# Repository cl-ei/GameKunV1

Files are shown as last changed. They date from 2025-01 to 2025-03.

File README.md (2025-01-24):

# GameKunV1
Magic Revised Tetris Palm

### 简介

这是一款魔改版的俄罗斯方块掌机，移除了原主板，换上了自制主板。自制主板选用高性能的 stm32H7 作为主控，通过电阻分压网络驱动液晶屏，还添加了 TAS2563 音频功放芯片来驱动扬声器，实现了声色俱全的效果，支持编写自制游戏。

This is a modified version of the Tetris handheld game console. The original motherboard has been removed and replaced with a self - made one. The self - made motherboard uses the high - performance STM32H7 as the main control unit. It drives the liquid crystal display through a resistor voltage - dividing network. Additionally, a TAS2563 audio power amplifier chip is added to drive the speaker, achieving a full - fledged audio - visual effect. It also supports the development of self - made games.

图纸有几处错误：
1. 音频功放的部分使用SAI接口，但若使用H723芯片，则该接口对应的SAI模块不支持半传输DMA中断，因此使用跳线连接到I2S1接口；
2. 原本预留了一个ADC通道，用于连接模拟麦克风，但若使用H723芯片，对应通道不支持半传输中断；
3. 主板上集成一颗MPU6050传感器，但电路绘制错误，芯片焊上不可用；
3. 没有兼容原机的电池座

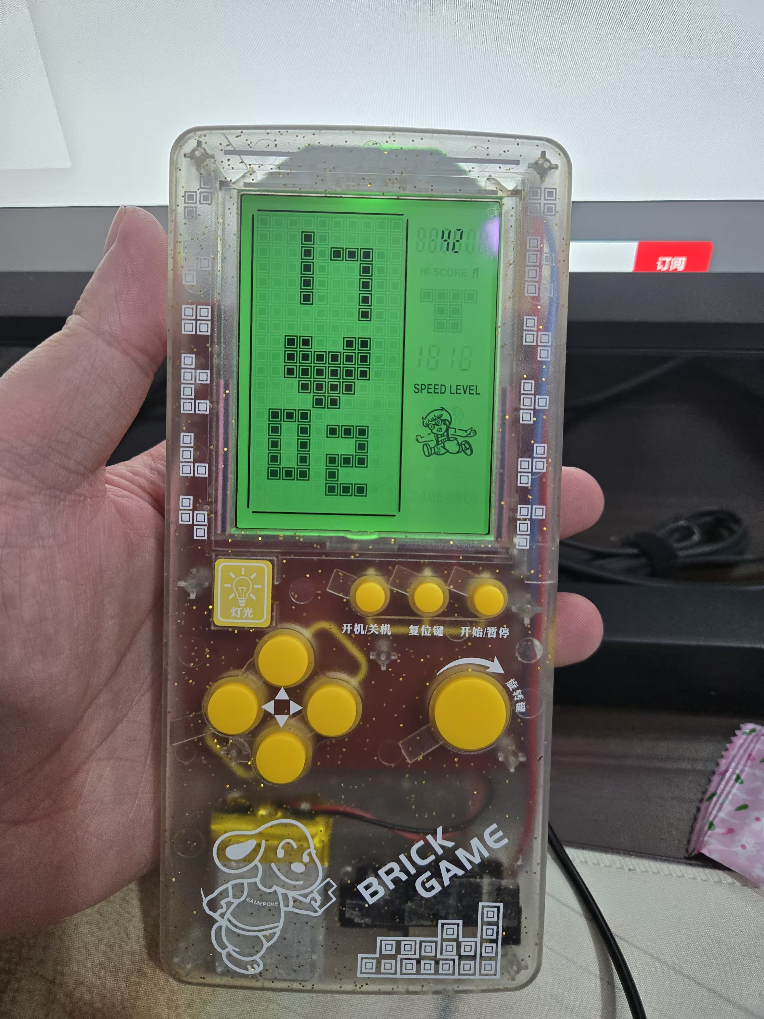
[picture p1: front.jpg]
预览

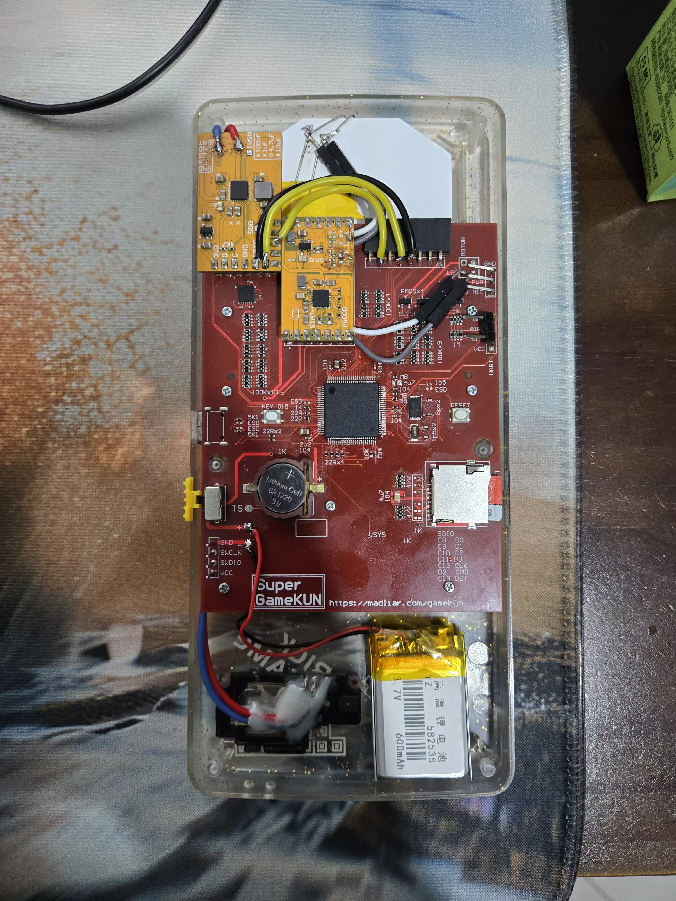
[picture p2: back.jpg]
预览2


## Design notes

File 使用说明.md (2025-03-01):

预览

1. 开/关机

推动右侧开关，自动进入开机模式，展示时钟。时钟会自动同步网络时间，保持精准。

2. 连接网络

用Type-C数据线连接电脑，然后按住“开始/暂停键”，直到屏幕显示USB图标，此时电脑上会多出一个大容量存储的设备。此过程可能较为漫长，需耐心等待。

打开大容量存储设备，根目录下会有一个“wifi.txt”文件（若没有，就自行创建），文件名区分大小写。在这个文件内写入WiFi的名称（ssid）和密码，用“*”相隔。注意WiFi名不可以包含英文星号“*”。

例如，WiFi名为“madliar”，密码为“password”，则在文件内写入“madliar*password”。又如，WiFi名称为“madliar”，密码为“1234*abc”，则在文件内写入“madliar*1234*abc”。

保存之后，按住“开始/暂停键”，退出USB模式后，重新开关机，即可以自动联网获取时间。

在首次开机时，系统会自动同步网络时间，此后每间隔2小时同步一次。同步成功时，设备后部顶端的LED灯会闪烁。

3. 手动调整时间

在时钟模式下，长按“复位键”，小时数会闪烁。此时按上、下键调整数字。再短按复位键，分钟数开始闪烁，按照同样的方法调整分钟，再按复位键，会退回到时钟模式。

4. MP3功能

时钟模式下，按住“旋转键”会进入音乐播放器模式。此时上下键调整音量，左右键切换歌曲，旋转键控制播放、暂停。再次长按旋转键，系统退出MP3播放器。

使用2中链接到电脑的方式，可以从电脑上下载音乐到设备中，但需注意，此设备仅支持wav格式，码率为44.1Khz或48Khz。

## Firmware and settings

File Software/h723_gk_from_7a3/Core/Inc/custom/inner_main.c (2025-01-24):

#include "inner_main.h"
#include "stm32h7xx_hal.h"
#include "debug.h"

#include "usb_device.h"
#include "usbd_msc.h"
#include "usbd_desc.h"
#include "usbd_storage_if.h"

#include "custom/ff15/ff.h"

#include "tas2563.h"
#include "logic/display.h"
#include "logic/mevent.h"
#include "logic/maudio.h"

extern TIM_HandleTypeDef htim3;
extern RTC_HandleTypeDef hrtc;


u8 sysHour = 0;
u8 sysMin = 0;
u8 sysSec = 0;
u16 sysMicSec = 0;
u8 sysBtnTick = 0;

void HAL_TIM_PeriodElapsedCallback(TIM_HandleTypeDef *htim) {
	if (htim->Instance == TIM3){
		// every 1ms
		sysMicSec++;
		if (sysMicSec >= 1000) {
			sysMicSec = 0;
			sysSec++;
			if (sysSec >= 60) {
				sysSec = 0;
				sysMin++;
				if (sysMin >= 60) {
					sysMin=0;
					sysHour++;
					if (sysHour >= 24) {
						sysHour = 0;
					}
				}
			}
		}

		// check button
		sysBtnTick++;
		if (sysBtnTick >= 3) {
			sysBtnTick = 0;
			Event_CheckButton();
		}

		// flush lcd
		SegLcd_DrawOneFrame();
	}
}

// USB
extern USBD_HandleTypeDef hUsbDeviceHS;

i8 CL_USB_DEVICE_Init(void) {
	if (USBD_Init(&hUsbDeviceHS, &HS_Desc, DEVICE_HS) != USBD_OK) {
		return -1;
	}
	if (USBD_RegisterClass(&hUsbDeviceHS, &USBD_MSC) != USBD_OK) {
		return -1;
	}
	if (USBD_MSC_RegisterStorage(&hUsbDeviceHS, &USBD_Storage_Interface_fops_HS) != USBD_OK) {
		return -1;
	}

	if (USBD_Start(&hUsbDeviceHS) != USBD_OK) {
		return -1;
	}
	HAL_PWREx_EnableUSBVoltageDetector();
	return 0;
}


i8 CL_USB_Device_DeInit() {
	HAL_PWREx_DisableUSBVoltageDetector ();

	if (USBD_Stop(&hUsbDeviceHS) != 0) {
		return -1;
	}
	return USBD_DeInit(&hUsbDeviceHS);
}

i8 SetSysFreq(u8 isHigh) {
	u8 rst = 0;

	HAL_PWREx_ConfigSupply(PWR_LDO_SUPPLY);
	if (isHigh) {
		__HAL_PWR_VOLTAGESCALING_CONFIG(PWR_REGULATOR_VOLTAGE_SCALE0);
	} else {
		__HAL_PWR_VOLTAGESCALING_CONFIG(PWR_REGULATOR_VOLTAGE_SCALE3);
	}

	while(!__HAL_PWR_GET_FLAG(PWR_FLAG_VOSRDY)) {}

	// config pll
	RCC_ClkInitTypeDef RCC_ClkInitStruct = {0};
	RCC_ClkInitStruct.ClockType = RCC_CLOCKTYPE_HCLK|RCC_CLOCKTYPE_SYSCLK
								  |RCC_CLOCKTYPE_PCLK1|RCC_CLOCKTYPE_PCLK2
								  |RCC_CLOCKTYPE_D3PCLK1|RCC_CLOCKTYPE_D1PCLK1;
	RCC_ClkInitStruct.SYSCLKSource = RCC_SYSCLKSOURCE_PLLCLK;

	if (isHigh) {
	  RCC_ClkInitStruct.SYSCLKDivider = RCC_SYSCLK_DIV1;
	} else {
	  RCC_ClkInitStruct.SYSCLKDivider = RCC_SYSCLK_DIV16;
	}

	RCC_ClkInitStruct.AHBCLKDivider = RCC_HCLK_DIV2;
	RCC_ClkInitStruct.APB3CLKDivider = RCC_APB3_DIV2;
	RCC_ClkInitStruct.APB1CLKDivider = RCC_APB1_DIV2;
	RCC_ClkInitStruct.APB2CLKDivider = RCC_APB2_DIV2;
	RCC_ClkInitStruct.APB4CLKDivider = RCC_APB4_DIV2;
	if (isHigh) {
		rst = HAL_RCC_ClockConfig(&RCC_ClkInitStruct, FLASH_LATENCY_3);
	} else {
		rst = HAL_RCC_ClockConfig(&RCC_ClkInitStruct, FLASH_LATENCY_0);
	}
	if (rst != HAL_OK) {
		print("sys clk config error: %d", rst);
		return -1;
	}
	print("sys clk config ok.");

	// 需要设置 TIM3的频率
	HAL_TIM_Base_Stop_IT(&htim3);
	HAL_TIM_Base_DeInit(&htim3);

	TIM_ClockConfigTypeDef sClockSourceConfig = {0};
	TIM_MasterConfigTypeDef sMasterConfig = {0};

	htim3.Instance = TIM3;
	if (isHigh) {
		htim3.Init.Prescaler = 240-1;
	} else {
		htim3.Init.Prescaler = 15-1;
	}

	htim3.Init.CounterMode = TIM_COUNTERMODE_UP;
	htim3.Init.Period = 1000;
	htim3.Init.ClockDivision = TIM_CLOCKDIVISION_DIV1;
	htim3.Init.AutoReloadPreload = TIM_AUTORELOAD_PRELOAD_ENABLE;
	rst = HAL_TIM_Base_Init(&htim3);
	if (rst != HAL_OK) {
		print("tim error: %d", rst);
		return -1;
	}

	sClockSourceConfig.ClockSource = TIM_CLOCKSOURCE_INTERNAL;
	rst = HAL_TIM_ConfigClockSource(&htim3, &sClockSourceConfig);
	if (rst != HAL_OK) {
		print("tim clk config error: %d", rst);
		return -1;
	}

	sMasterConfig.MasterOutputTrigger = TIM_TRGO_RESET;
	sMasterConfig.MasterSlaveMode = TIM_MASTERSLAVEMODE_DISABLE;
	rst = HAL_TIMEx_MasterConfigSynchronization(&htim3, &sMasterConfig);
	if (rst != HAL_OK) {
		print("tim master config result: %d", rst);
	    return -1;
	}
	HAL_TIM_Base_Start_IT(&htim3);
	return 0;
}

// mode 0: rest
// 1. play
#define PLAYMODE_MAIN_PAGE  0
#define PLAYMODE_MP3        1
#define PLAYMODE_HOUR_SET_PAGE  2
#define PLAYMODE_MIN_SET_PAGE  3
#define PLAYMODE_USB_PAGE  4

u32 playMode = PLAYMODE_MAIN_PAGE;
u8 Mp3_SongCount = 0;
u8 Mp3_SongIndex = 0;
u8 Mp3_Volume = 2;

void Mp3_SetVol() {
	SegLcd_SetLevelValue(Mp3_Volume, 0);
	Audio_SetVol(Mp3_Volume);
}
extern u8 SegLcd_ShowMusic;
extern u8 SegLcd_Body;
extern u8 SegLcd_PrevBox;

i8 Mp3_Enter() {
	SegLcd_ShowMusic = 1;
	SegLcd_Body = 0;

	u8 result = Audio_Init();
	print("audio init result: %d", result);
	if (result != 0) {
		return result;
	}

	Mp3_SongCount = Audio_GetSongCount();
	SegLcd_SetTopValue(0, 2);
	result = Audio_Start(Mp3_SongIndex);
	if (result == 0) {
		Mp3_SetVol();
	}
	return result;
}

i8 Mp3_Exit() {
	SegLcd_ShowMusic = 0;
	SegLcd_Body = 0b101;
	SegLcd_PrevBox = 0;

	Scr_Clean();
	Scr_RenderTime(88, 88, 88); // 清除缓存，下次渲染刷新真实值
	SegLcd_SetLevelValue(Mp3_Volume, 1);
	i8 result = Audio_Stop();
	if (result != 0) {
		print("stop audio error: %d", result);
		return result;
	}
	return result;
}


u8 uartTxBuff[65];
u8 uartRxBuff[64];
u8 wifiConfLen = 0;
extern UART_HandleTypeDef huart2;

// 0 准备开机设置时间; 1. 等待m5开机; 2 发送并进入3; 3 检查时间，如果超过1个小时，则进入0 开始重新校准
u8 m5Status = 0;
u32 m5Tick = 0;

void HAL_UARTEx_RxEventCallback(UART_HandleTypeDef *huart, uint16_t Size) {
	if(huart == (&huart2)) {
		print("s: %d", Size);
		if (Size == 3 &&
			(uartRxBuff[0] & 0xC0) == 0xC0 &&
			(uartRxBuff[1] & 0x80) == 0x80 &&
			(uartRxBuff[2] & 0x40) == 0x40) {

			sysHour = uartRxBuff[0] & (~0xC0);
			sysMin = uartRxBuff[1] & (~0x80);
			sysSec = uartRxBuff[2] & (~0x40);
			m5Status = 4;
		}
		HAL_UARTEx_ReceiveToIdle_DMA(&huart2, uartRxBuff, 32);
	}
}

void CheckNetTime(u32 tick) {
	u8 rst = 0;

	// 准备
	if (m5Status == 0) {
		m5Status = 1;
		HAL_GPIO_WritePin(GPIOA, GPIO_PIN_15, GPIO_PIN_RESET);
		m5Tick = tick;
	} else if (m5Status == 1) {
		if ((tick - m5Tick) > 5000) {
			m5Status = 2;
		}
	} else if (m5Status == 2) {
		for (i8 i = 0; i < 8; i++) {
			rst = HAL_UART_Receive(&huart2, uartRxBuff, 32, 0x1);
			print("receive rst: %d");
			if (rst != 0) {
				break;
			}
		}
		rst = HAL_UARTEx_ReceiveToIdle_DMA(&huart2, uartRxBuff, 32);
		print("set idle: %d", rst);

		rst = HAL_UART_Transmit(&huart2, uartTxBuff, wifiConfLen, 0xFFFF);
		print("wifi conf tx: %d, len: %d", rst, wifiConfLen);

		m5Status = 3;
	} else if (m5Status == 3) {
	} else if (m5Status == 4) {
		// close m5
		HAL_GPIO_WritePin(GPIOA, GPIO_PIN_15, GPIO_PIN_SET);

		RTC_TimeTypeDef realTime;
		realTime.Hours = sysHour;
		realTime.Minutes = sysMin;
		realTime.Seconds = sysSec;
		u8 rst = HAL_RTC_SetTime(&hrtc, &realTime, RTC_FORMAT_BIN);
		print("set ntp rst: %d", rst);

		m5Status = 5;
	} else if (m5Status == 5) {
		if ((tick - m5Tick) > (1000 * 7200)) {
			m5Status = 0;
		}
	}
}

i8 loadWifiPass() {
	FIL tmpFile;
	FRESULT fr;
	UINT br = 0;
	TCHAR fno[9] = {'w', 'i', 'f', 'i', '.', 't', 'x', 't', '\0'};

	u8 rst = Audio_Init();
	if (rst != 0) {
		print("mount err: %d", rst);
		return rst;
	}
	fr = f_open(&tmpFile, fno, FA_READ | FA_OPEN_EXISTING);
	if (fr != FR_OK) {
		print("open wifi conf err: %d", fr);
		return -1;
	}
	fr = f_read(&tmpFile, (void *)uartTxBuff, 63, &br); // 抛弃最起始的100个字节
	if (fr != FR_OK) {
		print("read err: %d", fr);
		return -1;
	}
	print("read br: %d", br);
	wifiConfLen = (br >= 63) ? 63 : br;
	uartTxBuff[64] = 0;
	print(uartTxBuff);
	return 0;
}

void CheckBgLight(u32 tick) {
	static u32 bgLightTick = 0;
	if (tick - bgLightTick > 200) {
		bgLightTick = tick;
		SegLcd_SetBGLight((Event_GetLastEventDur() < 15000) ? 1 : 0);
	}
}

u8 EventLoopMainPage() {
	u32 tick;
	u8 rst;
	u8 event;
	u8 retMode = 0;

	Scr_Clean();
	Scr_RenderTime(88, 88, 88); // 清除缓存，下次渲染刷新真实值

	rst = SetSysFreq(0);
	print("set low pwr rst: %d", rst);

	// update time
	RTC_TimeTypeDef realTime;
	RTC_DateTypeDef sDate;
	rst = HAL_RTC_GetTime(&hrtc, &realTime, RTC_FORMAT_BIN);
	HAL_RTC_GetDate(&hrtc, &sDate, RTC_FORMAT_BIN);
	sysHour = realTime.Hours;
	sysMin = realTime.Minutes;
	sysSec = realTime.Seconds;

	while (1) {
		tick = HAL_GetTick();
		CheckBgLight(tick);
		event = Event_Get();

		CheckNetTime(tick);
		Scr_RenderTime(sysHour, sysMin, sysSec);

		if (event == EVENT_KEY_SPIN_LONG) {
			rst = Mp3_Enter();
			if (rst == 0) {
				return PLAYMODE_MP3;
			} else {
				print("process error: %d", rst);
			}
		} else if (event == EVENT_KEY_RST_LONG) {
			return PLAYMODE_HOUR_SET_PAGE;
		} else if (event == EVENT_KEY_START_LONG) {
			return PLAYMODE_USB_PAGE;
		}
	}
}

u8 EventLoopMP3() {
	u32 tick;
	u8 rst;
	u8 event;

	rst = SetSysFreq(1);
	print("set high pwr rst: %d", rst);
	rst = Mp3_Enter();
	if (rst != 0) {
		return PLAYMODE_MAIN_PAGE;
	}
	while (1) {
		tick = HAL_GetTick();
		CheckBgLight(tick);
		event = Event_Get();

		Audio_RenderUI(tick);
		Audio_LoadBuff();

		if (event == EVENT_KEY_SPIN) {
			if(Audio_IsPlaying()){
				Audio_Pause();
			} else {
				Audio_Play();
			}
		} else if (event == EVENT_KEY_UP) {
			if (Mp3_Volume < 10) {
				Mp3_Volume++;
			}
			Mp3_SetVol();
		} else if (event == EVENT_KEY_DOWN) {
			if (Mp3_Volume > 0) {
				Mp3_Volume--;
			}
			Mp3_SetVol();
		} else if (event == EVENT_KEY_LEFT) {
			Audio_Stop();
			if (Mp3_SongIndex == 0) {
				Mp3_SongIndex = Mp3_SongCount - 1;
			} else {
				Mp3_SongIndex--;
			}
			Audio_Start(Mp3_SongIndex);
			SegLcd_SetTopValue(Mp3_SongCount*100 + Mp3_SongIndex + 1, 0);
		} else if (event == EVENT_KEY_RIGHT || event == EVENT_MUSIC_END) {
			Audio_Stop();
			Mp3_SongIndex++;
			if (Mp3_SongIndex >= Mp3_SongCount) {
				Mp3_SongIndex = 0;
			}
			Audio_Start(Mp3_SongIndex);
			SegLcd_SetTopValue(Mp3_SongCount*100 + Mp3_SongIndex + 1, 0);
		} else if (event == EVENT_KEY_SPIN_LONG) {
			rst = Mp3_Exit();
			if (rst == 0) {
				return PLAYMODE_MAIN_PAGE;
			} else {
				print("exit mp3 error: %d", rst);
			}
		}
	}
}

u8 EventLoopHourSet() {
	u32 tick;
	u8 event;

	SetSysFreq(0);

	while (1) {
		tick = HAL_GetTick();
		CheckBgLight(tick);
		event = Event_Get();

		Scr_FlashHourMin(tick, sysHour, sysMin, sysSec, 0);
		if (event == EVENT_KEY_RST) {
			return PLAYMODE_MIN_SET_PAGE;
		} else if (event == EVENT_KEY_UP) {
			sysHour = sysHour == 23 ? 0 : (sysHour + 1);
		} else if (event == EVENT_KEY_DOWN) {
			sysHour = sysHour == 0 ? 23 : (sysHour - 1);
		}
	}
}

u8 EventLoopMinSet() {
	u32 tick;
	u8 event;
	u8 rst;

	SetSysFreq(0);

	while (1) {
		tick = HAL_GetTick();
		CheckBgLight(tick);
		event = Event_Get();

		Scr_FlashHourMin(tick, sysHour, sysMin, sysSec, 1);

		if (event == EVENT_KEY_RST) {
			RTC_TimeTypeDef realTime;
			realTime.Hours = sysHour;
			realTime.Minutes = sysMin;
			realTime.Seconds = sysSec;
			rst = HAL_RTC_SetTime(&hrtc, &realTime, RTC_FORMAT_BIN);
			if (rst != 0) {
				print("set failed: %d", rst);
			} else {
				return PLAYMODE_MAIN_PAGE;
			}
		} else if (event == EVENT_KEY_UP) {
			sysMin = sysMin == 59 ? 0 : (sysMin + 1);
		} else if (event == EVENT_KEY_DOWN) {
			sysMin = sysMin == 0 ? 59 : (sysMin - 1);
		}
	}
}

u8 EventLoopUSB() {
	u32 tick;
	u8 event;

	SetSysFreq(1);
	CL_USB_DEVICE_Init();

	Scr_RenderUSBPage();

	while (1) {
		tick = HAL_GetTick();
		CheckBgLight(tick);
		event = Event_Get();

		if (event == EVENT_KEY_START_LONG) {
			CL_USB_Device_DeInit();
			return PLAYMODE_MAIN_PAGE;
		}
	}
}

void myMain() {
	uint32_t tick = 0;
	u8 event = 0;
	i8 rst = 0;
	print("enter myMain.");

	Event_Init();
	HAL_TIM_Base_Start_IT(&htim3);

	CL_SD_Init();
	rst = loadWifiPass();
	print("wifi load rst: %d", rst);

	// 开启 LCD
	SegLcd_Init();
	SegLcd_SetBGLight(1);

	// 开启时钟计时
	SetSysFreq(0);
	print("enter main loop.");

	HAL_Delay(500);
	while (1) {
		if (playMode == PLAYMODE_MAIN_PAGE) {
			playMode = EventLoopMainPage();
		} else if (playMode == PLAYMODE_MP3) {
			playMode = EventLoopMP3();
		} else if (playMode == PLAYMODE_HOUR_SET_PAGE) {
			playMode = EventLoopHourSet();
		} else if (playMode == PLAYMODE_MIN_SET_PAGE) {
			playMode = EventLoopMinSet();
		} else if (playMode == PLAYMODE_USB_PAGE) {
			playMode = EventLoopUSB();
		}
	} // end of while(1)
}

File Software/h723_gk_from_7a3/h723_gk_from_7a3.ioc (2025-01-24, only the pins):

Mcu.UserName=STM32H723VGTx
PA0.Signal=UART4_TX
PA1.Signal=UART4_RX
PA10.Signal=GPIO_Output
PA11.Signal=USB_OTG_HS_DM
PA12.Signal=USB_OTG_HS_DP
PA15(JTDI).Signal=GPIO_Output
PA2.Signal=USART2_TX
PA3.Signal=USART2_RX
PA4.Signal=I2S1_WS
PA5.Signal=I2S1_CK
PA7.Signal=I2S1_SDO
PA9.Signal=GPIO_Output
PB10.Signal=I2C2_SCL
PB11.Signal=I2C2_SDA
PC0.Signal=GPIO_Input
PC1.Signal=GPIO_Input
PC10.Signal=SDMMC1_D2
PC11.Signal=SDMMC1_D3
PC12.Signal=SDMMC1_CK
PC14-OSC32_IN.Signal=RCC_OSC32_IN
PC15-OSC32_OUT.Signal=RCC_OSC32_OUT
PC2_C.Signal=GPIO_Input
PC5.Signal=GPIO_Input
PC6.Signal=GPIO_Input
PC7.Signal=GPIO_Input
PC8.Signal=SDMMC1_D0
PC9.Signal=SDMMC1_D1
PD0.Signal=GPIO_Input
PD1.Signal=GPIO_Input
PD15.Signal=GPIO_Input
PD2.Signal=SDMMC1_CMD
PH0-OSC_IN.Signal=RCC_OSC_IN
PH1-OSC_OUT.Signal=RCC_OSC_OUT

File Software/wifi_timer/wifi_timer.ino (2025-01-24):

#include <WiFi.h>
#include <NTPClient.h>
#include <FastLED.h>

#define DATA_PIN 27
#define NUM_LEDS 1
CRGB leds[NUM_LEDS];

const char* ntpServer = "pool.ntp.org";
WiFiUDP ntpUDP;
NTPClient timeClient(ntpUDP, ntpServer);

void setup() {
  Serial.begin(115200);
  while(!Serial);

  String ssid = "";
  String pass = "";

  bool readSplit = false;

  while (1) {
    if (Serial.available()) {
      while (Serial.available() > 0) {
        char c = Serial.read();
        if (readSplit == false && c == '*') {
          readSplit = true;
          continue;
        }
        if (readSplit) {
          pass += c;
        } else {
          ssid += c;
        }
      }
      break;
    }
  }
  WiFi.begin(ssid, pass);
  
  while (WiFi.status() != WL_CONNECTED) {
    delay(500);
  }

  timeClient.begin();

  leds[0] = 0xFF0f0FF;
  FastLED.addLeds<SK6812, DATA_PIN, RGB>(leds, NUM_LEDS);  // GRB ordering is typical
  FastLED.show();
}

unsigned char txBuff[3];

void loop() {
  timeClient.update();
 
  unsigned long epochTime = timeClient.getEpochTime();
  if (epochTime < 10000) {
    delay(500);
    return;
  }

  unsigned char hour = timeClient.getHours() + 8;
  unsigned char minu = timeClient.getMinutes();
  unsigned char sec = timeClient.getSeconds();
  txBuff[0] = 0xC0 | hour;
  txBuff[1] = 0x80 | minu;
  txBuff[2] = 0x40 | sec;
  Serial.write(txBuff, 3);
  delay(5000);
}

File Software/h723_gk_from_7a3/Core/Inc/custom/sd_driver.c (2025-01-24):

#include "sd_driver.h"
#include "debug.h"

extern SD_HandleTypeDef hsd1;
#define opHsd hsd1

#define SD_TIMEOUT                  ((uint32_t)0xFFFFFFFFU)

HAL_SD_CardInfoTypeDef CL_pCardInfo;
static uint8_t CL_sdIsTransmiting = 0;
static uint8_t SD_Inited = 0;

void HAL_SD_ErrorCallback(SD_HandleTypeDef *hsd) {
	print("sd err!");
	CL_sdIsTransmiting = 0;
	if(hsd->State != HAL_SD_STATE_ERROR){
		hsd->State = HAL_SD_STATE_ERROR;
	}
}

void HAL_SD_RxCpltCallback(SD_HandleTypeDef *hsd){
	CL_sdIsTransmiting = 0;
}

void HAL_SD_TxCpltCallback(SD_HandleTypeDef *hsd){
	CL_sdIsTransmiting = 0;
}

int8_t CL_SD_Init(void) {
	if (SD_Inited) {
		return 0;
	}
	SD_Inited = 1;

	hsd1.Instance = SDMMC1;
	hsd1.Init.ClockEdge = SDMMC_CLOCK_EDGE_RISING;
	hsd1.Init.ClockPowerSave = SDMMC_CLOCK_POWER_SAVE_DISABLE;
	hsd1.Init.BusWide = SDMMC_BUS_WIDE_4B;
	hsd1.Init.HardwareFlowControl = SDMMC_HARDWARE_FLOW_CONTROL_DISABLE;
	hsd1.Init.ClockDiv = 0;
	return HAL_SD_Init(&opHsd);
}
int8_t CL_SD_DeInit(void) {
	SD_Inited = 0;
	return HAL_SD_DeInit(&opHsd);
}

HAL_StatusTypeDef CL_getSDState() {
	HAL_SD_CardStateTypeDef status;
	status = HAL_SD_GetCardState(&opHsd);
	if (status == HAL_SD_CARD_ERROR) {
		print("sd error status: %x\n", status);
		return HAL_ERROR;
	}

	return HAL_OK;
}

HAL_StatusTypeDef CL_readSdInfo(){
	HAL_SD_CardCIDTypedef CL_pCID;
	HAL_SD_CardCSDTypedef CL_pCSD;
	HAL_StatusTypeDef status = HAL_OK;

	status = HAL_SD_GetCardCID(&opHsd, &CL_pCID);
	if (status != HAL_OK){
		print("cid read err: %x\n", status);
		return status;
	}
	status = HAL_SD_GetCardCSD(&opHsd, &CL_pCSD);
	if (status != HAL_OK){
		print("csd read err: %x\n", status);
		return status;
	}
	status = HAL_SD_GetCardInfo(&opHsd, &CL_pCardInfo);
	if (status != HAL_OK){
		print("card info read err: %x\n", status);
		return status;
	}
	CL_pCardInfo.BlockNbr = CL_pCardInfo.BlockNbr;
	return HAL_OK;
}

HAL_StatusTypeDef CL_sdReadBlocks(uint8_t *pData, uint32_t BlockAdd, uint32_t NumberOfBlocks){
	HAL_StatusTypeDef status;
	uint32_t start_time;

	// 等待SD状态由忙转为就绪态
	start_time = HAL_GetTick();
	while(HAL_SD_GetCardState(&opHsd) != HAL_SD_CARD_TRANSFER) {
		if ((HAL_GetTick() - start_time) >= SD_TIMEOUT) {
			return HAL_ERROR;
		}
	}

	// 启动传输
	CL_sdIsTransmiting = 1;
	status = HAL_SD_ReadBlocks_DMA(&opHsd, pData, BlockAdd, NumberOfBlocks);
	if (status != HAL_OK) {
		return status;
	}

	// 启动DMA成功，等待读完成。在DMA完成中断HAL_SD_RxCpltCallback中，会将CL_sdIsTransmiting置为0
	start_time = HAL_GetTick();
	while(CL_sdIsTransmiting == 1) {
		if((HAL_GetTick() - start_time) >= SD_TIMEOUT) {
			return HAL_ERROR;
		}
	}
	return HAL_OK;
}

HAL_StatusTypeDef CL_sdWriteBlocks(uint8_t *pData, uint32_t BlockAdd, uint32_t NumberOfBlocks){
	HAL_StatusTypeDef status;
	uint32_t start_time;

	// 等待SD状态由忙转为就绪态
	start_time = HAL_GetTick();
	while(HAL_SD_GetCardState(&opHsd) != HAL_SD_CARD_TRANSFER) {
		if ((HAL_GetTick() - start_time) >= SD_TIMEOUT) {
			return HAL_ERROR;
		}
	}

	// 启动DMA传输
	CL_sdIsTransmiting = 1;
	status = HAL_SD_WriteBlocks_DMA(&opHsd, pData, BlockAdd, NumberOfBlocks);
	if (status != HAL_OK) {
		return status;
	}

	// 启动DMA成功，等待读完成。在DMA完成中断HAL_SD_TxCpltCallback中，会将CL_sdIsTransmiting置为0
	start_time = HAL_GetTick();
	while(CL_sdIsTransmiting == 1) {
		if((HAL_GetTick() - start_time) >= SD_TIMEOUT) {
			return HAL_ERROR;
		}
	}

	return HAL_OK;
}
